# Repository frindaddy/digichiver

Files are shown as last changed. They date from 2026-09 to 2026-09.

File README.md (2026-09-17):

# Digichiver

Digichiver is an open hardware and software platform for operating, emulating,
and archiving the audio output of the National Semiconductor MM54104 Mozer
Digitalker speech synthesis system. The board can drive a physical MM54104,
serve historical speech ROM images through an RP2354B-based ROM emulator, and
record the resulting audio to a microSD card. Archived audio outputs are
available in the [Digitalker audio archive repository](https://github.com/frindaddy/digitalker-audio-archive).



## Repository Layout

The repository is organized by the part of the project it describes:

- `Hardware/` contains the KiCad schematics, PCB layout, custom footprints,
	fabrication outputs, and hardware design notes. Start with
	[`Hardware/readme.md`](Hardware/readme.md) for the circuit description.
- `Software/` contains the MicroPython firmware modules, ROM images, speech
	dictionaries, and archive configuration. Start with
	[`Software/readme.md`](Software/readme.md) for deployment and operation.
- `Simulation/` contains LTspice simulations for the analog speech filter.
- `DesignDocs/` contains project requirements and system architecture notes.
- `Datasheets/` contains component and reference documentation used by the
	design.
- `LICENSE` contains the project license.

## Using Digichiver

Digichiver requires the assembled board, an MM54104 Digitalker chip, and the
required ROM files for the speech vocabulary being used. The board is powered
and programmed over USB-C. Install the supplied
`Software/digichiver_firmware.uf2` firmware using the RP2354B USB bootloader,
then copy the required Python modules, ROM images, and JSON dictionaries from
`Software/` to the board's MicroPython filesystem.

After reset, connect to the board's MicroPython REPL. The software starts an
interactive `digichiver>` command loop for loading ROMs, speaking words,
checking word indexes, and archiving ROM groups to an inserted microSD card.
The complete command reference and file-deployment requirements are documented
in [`Software/readme.md`](Software/readme.md).

The hardware design can be opened with KiCad. The firmware `digitalker_firmware.u2f`
targets MicroPython on the RP2354B.

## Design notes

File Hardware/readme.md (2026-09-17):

# Circuit Description

The doc describes the digichicver circuit schematic (and PCB layout, when needed).

## Block Diagram

This sheet show the block diagram for the Digichiver board. The sheet is broken into 4 sections, the USB-C power/data connector, the Control block, the Digitalker block, the Audio block, and the Power block.

The USB-C connector is setup for a USB 2.0 full-speed connection, as that is the max capability of the RP2354B. Two $5.1k\Omega$ resistors tie `CC1` and `CC2` to ground to specify that this board is a power sink, per the USB specification. This advertises that this board can consume a maximum of 2.5W (5V@500mA).

## Control

This sheet shows the RP2354B and microSD card, as well as their supporting circuitry and pinouts.

### RP2354B

The RP2354B is the MCU on the Digichiver board and is used to control the MM54104 Digitalker chip, emulate Digitalker ROM modules, and record the Digitalker output audio to the microSD card (plus other basic GPIO functions). It interfaces with the MM54104 Digitalker chip, microSD card, and the PCM1809 audio recorder. The RP2354B has 2MB of internal flash in chip, so an external flash module is not required for operation.

#### RP2354B Power and Decoupling

The RP2354B nominally runs off a +3V3 supply, but requires a +1V1 rail for internal functions. Unlike its predecessor (the RP2340), the RP2354B ships with a built in switching regulator to generate this +1V1 rail in package, with the help of some supporting components. The design and layout of this power supply is strictly defined in [Hardware Design with the RP2350](https://pip-assets.raspberrypi.com/categories/1214-rp2350/documents/RP-008280-DS-1-hardware-design-with-rp2350.pdf), and the design recommendations were replicated here (part selection, connections, and layout).

Decoupling capacitors were placed based on the recommendations of [Hardware Design with the RP2350](https://pip-assets.raspberrypi.com/categories/1214-rp2350/documents/RP-008280-DS-1-hardware-design-with-rp2350.pdf); one for each power pin, and a special 4.7uF bulk cap for the +1V1 rail.

#### RP2354B USB Connection

The RP2354B is only capable of USB full speed (USB 2.0, 12Mbps, 48MHz clock). Though this is pretty slow speed, an attempt was made to keep the characteristic impedance of the USB traces close to the USB specification of $90\Omega$, differential. This board isn't being built with controlled impedances, so *rough* numbers are used for the calculation. To find the required trace width for a $90\Omega$ differential impedance, $Z_d$, we use the edge-coupled microstrip impedance equation.

$$Z_d \approx \frac{174}{\sqrt{\epsilon_r + 1.41}} \times \ln(\frac{5.98h}{0.8w + t}) \times [1-0.48^{-0.96\frac{s}{h}}]$$

where $Z_d$ is the differential impedance, $t$ is the trace thickness, $h$ is the height of the dielectric between the microstrip and ground plane, $s$ is the trace spacing, $\epsilon_r$ is the dielectric constant of the material, and $w$ is the trace width. The rough numbers are derived from the general JLCPCB 4 layer TG135 stackup and their manufacturing capabilities: $Z_d = 90\Omega$, $t = 1oz/ft^2$, $h = 8.283mil$, $s = 10mil$, and $\epsilon_r = 4.5$. Using these numbers, we calulate that the ideal trace width to achieve a $90\Omega$ differential impedance is `12.3645mil`.

$27\Omega$ series termination resistors are placed on the USB lines close to the RP2354B to meet the USB impedance specification.

#### RP2354B Clock

The RP2354B does not need an external clock to function (it ships with an internal oscillator), but a stable external frequency source greatly improves peripheral reliability and performance. As such, an external 12MHz crystal oscillator is used to clock the RP2354B. Part selection and circuit design are from the recommendations in [Hardware Design with the RP2350](https://pip-assets.raspberrypi.com/categories/1214-rp2350/documents/RP-008280-DS-1-hardware-design-with-rp2350.pdf).

#### Programming and Reset

Two pushbuttons, `SW1` and `SW2` are used to program and reset the RP2354B, respectively. When `SW1` is pressed on power up, the `QSPI_SS` line to the RP2354B is driven low, placing the device into programming mode. It will show up as a USB storage device, and a bootloader can be loaded into internal memory.

During operation, `SW2` can be pressed to reset the RP2354B by driving the `RUN` pin low.

#### Interfaces and GPIO

The MM54104 Digitalker control and ROM emulation busses take up most of the GPIO pins on the RP2354B. These signals are broken out as follows:

MM54104 Control Signals

| Signal | I/O | Pin Count |
| --- | --- | --- |
| SPC Word Selection Bus | O | 8 |
| SPC Chip Select | O | 1 |
| SPC Command Select | O | 1 |
| SPC Write Strobe | O | 1 |
| SPC Interrupt | I | 1 |

MM54104 ROM Emulation

| Signal | I/O | Pin Count |
| --- | --- | --- |
| ROM Address Bus | I | 14 |
| ROM Data Bus | O | 8 |
| ROMEN | I | 1 |

Because the MM54104 operates on +5V logic levels, these signals require level shifting. The level shifters are found on the Digitalker sheet.

An I2S interface connects the PCM1809 audio ADC to the RP2354B.

An SPI interface connects the RP2354B to the microSD card port.

One pushbutton, one green "Ready" LED, and one yellow "Activity" LED are connected to the RP2354B as GPIO.

### microSD Card

The RP2354B has an SPI connection to the microSD card header. An SPI connection was selected over the typical SDIO connection for a few reasons: all microSD cards support SPI communication, the higher speeds of the SDIO interface are not required for this application, and the SPI interface requries 4 pins instead of 6. The SPI bus connects to the SPI1 peripheral on the RP2354B, per the [RP2354B datasheet](https://pip-assets.raspberrypi.com/categories/1214-rp2350/documents/RP-008373-DS-2-rp2350-datasheet.pdf). 10k pullup resistors are added on each SPI line to keep the bus in a known state on bootup.

The card detect line `SD_DET` is routed as a GPIO input to the RP2354B to check if a microSD card is actually inserted before writing to it. The physical mechanism in the microSD card slot is a mechanical switch that connects pin `9` to pin `10` when a card is inserted into the slot ([per DM3AT-SF-PEJM5 datasheet](https://www.hirose.com/product/document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)). When a card is not installed, the `SD_DET` line is pulled low by `R32`. When a microSD card is inserted into the slot, the `SD_DET` line is driven high to +3V3.

## Digitalker

This sheet shows the MM54104 Digitalker Speech Processing Chip IC socket (`XC1`), required level shifting, and speech output filtering.

### MM54104

The MM54104 is designed to be socketed on the board, rather than soldered directly. This helps protect the rare MM54104 from any soldering induced temperature stress, and keeps it easily replaceable in the case of failure due to age.

The MM54104 is powered by +9V, with a 100nF decoupling capacitor placed close to the power input pin.

The MM54104 requires an external 4MHz clock for operation. Rather than add additonal components to the BOM, the `OSC_IN` pin is connected to one of the RP2354B PWM output ports through a level shifter. The 4MHz clock is generated by the RP2354B PWM controller.

### Level Shifting

The MM54104 runs on a +7-11V power input, although uses +5V compatable TTL logic for its I/O connections. As such, level shifting is required between the +3V3 CMOS I/O from the RP2354B and the +5V TTL logic from the MM54104. This level shifting is accomplished using two different part numbers.

For the MM54104 → RP2354B connections, the SN74LVC245A is used. This level shifter operates on a single +3V3 rail, but has +5V tolerant inputs. This single supply architecture not only simplifies the power plane routing on the board, but also reduces the total input capacitance on the +5V rail[^1]. A total of two are required to shift the `ROM_ADDR[0..13]`, `ROMEN`, and `INTR` lines. The SN74LVC245As are configured as always enabled, A → B mode.

[^1]: The reduction of input capacitance is beneficial as the USB specification states that power sinking devices should have no more than 10uF of input capacitance on the +5V power rail to limit inrush current and prevent damaging the power sourcing device. With some quick napkin math, one can determine that this board nominally has 11.3uF of input capacitance on the +5V rail, plus whatever parasitic capacitance is added from the traces in the layout. Looking at the decoupling and bulk capacitors used on the +5V rail, the 10uF cap (`C31`) is $\pm$20%, and the 1uF cap (`C33`) and 100nF caps (`C5`, `C6`, `C7`) are $\pm$10%, therefore worst case input capacitance is `13.43uF`, plus whatever parasitic capacitance exists. After testing the board in real life, this doesn't seem to be a problem.  

For the RP2354B → MM54104 connections, the SN74LVCBT245 is used. This level shifter operates on split +3V3 and +5V rails. A total of three are required to shift the `DIGITALKER_CLK_4MHZ`, `DIGITALKER_CS`, `DIGITALKER_WR`, `DIGITALKER_CMS`, `SW[1..8]`, and `RDATA[0..7]` lines. The SN74LVCBT245s are configured as always enabled, A → B mode.

### Speech Output Filter

The speech output filter is designed to produce the maximum frequency response for the MM54104 speech output. It features a voltage rebiasing network to shift the output down to +3V3 tolerant levels, and a dual-stage Sallen-Key filter to match the filtering recommendations in the DT1050 datasheet.

First, a 1uF input capacitor is used to decouple the audio stream from the ~+4VDC "silence voltage" output by the MM54104. The audio stream is then rebiased to a +1V65 DC voltage offset through a pullup resistor (`R23`) to `V_BIAS`, which is generated with a 2:1 voltage divider. A 100nF decoupling capactior (`C42`) is used to keep `V_BIAS` clean from any switching noise that may exist on the +3V3 rail. The rebiased audio output then goes through the first Sallen-Key filter, which is a 7,234Hz low pass filter. The output of the low-pass filter goes into the next Sallen-Key filter, a 194Hz high-pass filter. Combined, the rebiasing and filtering produce the a similar frequency response to that recommended by the D1050 datasheet.

LTSpice simulations for this filtering circuit can be found in `Digichiver/Simulation`.

## Audio

This sheet contains the three audio output sources (audio ADC, 3.5mm jack, and onboard speaker) and their associated circuitry. All outputs are AC coupled to the filtered speech line through 1uF capacitors.

### Audio ADC

To record the audio stream to the microSD card, the RP2354B requires an external audio ADC connected via an I2S bus. The PCM1809 is used for this.

The PCM1809 has two stereo inputs, but the MM54104 produces only a single mono output. As such, only the positive input on channel 1 of the PCM1809 is connected, with the channel 1 negative input and both channel 2 inputs capacitively coupled to ground, per [the PCM1809 datasheet](https://www.ti.com/lit/ds/symlink/pcm1809.pdf?ts=1723810813788).

The PCM1809 is configured in I2S target mode, therefore the RP2354B controls the bus/chip. The RP2354B generates the `BCLK` and `FSYNC` signals, and the PCM1809 dynamically adjusts its sampling rate based on the `BCLK` to `FSYNC` ratio. The output data is sent on the `SDATA` line.

Decoupling capacitors are selected based on the typical application in [the PCM1809 datasheet](https://www.ti.com/lit/ds/symlink/pcm1809.pdf?ts=1723810813788).

### 3.5mm Jack

The 3.5mm jack provides an output source to external speaker amplifiers, if desired. To make the mono audio signal compatable with a stereo TRS jack, the audio is split to the tip (`T`) and ring (`R`) pins of the jack through $100\Omega$ resistors. The resistors prevent dead shorts between the T and R pins if a non TRS cable is inserted into the jack. A $100k\Omega$ resistor weakly pulls the line to ground to help prevent popping on cable connection/disconnection.

### Onboard Speaker

The onboard speaker `LS1` is driven using a stereo class-D amplifier IC, the PAM8302A. This amplifier is capable of driving an $8\Omega$ speaker at just under 800mW when powered by a +3V3 rail. As such, the $8\Omega$ 780mW CMS-2821-078T onboard speaker is a solid choice due to its matching specifications and reasonbly even frequency response.

Because the PAM8302A expects a stereo input, the mono MM54014 output is fed into the positive input channel and the negative input channel is capacitively coupled to ground.

`RV1` is a $10k\Omega$ logarithmic potentiometer used to control the ultimate volume of the onboard speaker.

A GPIO line `SPEAKER_MUTE` is routed to the RP2354B so the speaker can be disabled by software, when required.

## Power

This sheet shows the two switching power supplies responsible for deriving the +3V3 and +9V power rails from the +5V input rail. Both designs are based on a combination of the typical application diagrams in their respective datasheets and designs generated using the Texas Instruments [WEBENCH® Power Designer](https://webench.ti.com/power-designer/) tool.

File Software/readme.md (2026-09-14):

# Digichiver Software

The software in this directory runs the Digichiver board on MicroPython for
the RP2354B. It drives the MM54104 control bus, emulates its parallel ROM
interface, provides dictionary-based speech, and records speech through the
PCM1809 audio ADC to a microSD card.

## Software Layout

- `main.py` starts the interactive `digichiver>` command loop.
- `board.py` assigns the RP2354B GPIO, PWM, SPI, and I2S interfaces used by the
  board.
- `digitalker.py` drives the MM54104 word-selection bus and control signals.
- `rom_emulator.py` serves a selected ROM image using PIO and DMA without
  requiring Python to handle each ROM access.
- `free_speak.py` resolves text, aliases, numbers, and literal vocabulary
  fragments into Digitalker words.
- `archive.py` captures 48 kHz, 16-bit, mono PCM and writes WAV files to `/sd`.
- `sdcard.py` provides the SPI microSD-card driver.
- `Dictionaries/` contains the free-speak vocabulary, archive metadata, and
  index-to-word dictionaries.
- `ROMs/` contains the supplied ROM image collections and source indexes.
- `digichiver_firmware.uf2` is the firmware image for the RP2354B.

## Deployment

Install `digichiver_firmware.uf2` with the RP2354B USB bootloader. After the
board resets, copy the runtime files to the MicroPython filesystem. The
working directory matters because the software opens ROMs and JSON files by
filename, so the following files must be in one flat directory on the board:

```text
archive.py
archive_config.json
board.py
digitalker.py
free_speak.py
free_speak_dictionary.json
main.py
rom_emulator.py
sdcard.py
```

Copy the ROM files required by the selected operation into that same
directory. For `/say` and `/say_all`, also copy `DVSSROM1.bin` through
`DVSSROM5.bin`. For `/archive`, copy the source ROMs and dictionary files
named by `Dictionaries/archive_config.json`. Reset the board and connect to its
MicroPython REPL; `main.py` starts the command loop.

## ROM Emulator

`RomEmulator` presents a selected binary image as the MM54104's 16 KiB
parallel ROM. A single image may contain from 1 to 16 KiB. It is loaded at
address `0x0000` and zero-filled through `0x3fff`. Two-file images must contain
exactly 8 KiB per file and are concatenated in argument order.

```python
from rom_emulator import RomEmulator

rom = RomEmulator()
rom.load("DT1052.bin")
rom.load("SSR1.bin", "SSR2.bin")
```

`load()` validates the new files before stopping a currently running image.
An invalid reload leaves the previous image running. If the new image cannot
start, it remains selected but stopped. File paths are resolved from the
MicroPython working directory.

## Free Speak

`free_speak.py` maps text to the five DVSS ROMs and their word indexes. Input
is case-insensitive and runs of whitespace are collapsed. The complete input
is resolved before any ROM is loaded or word is spoken, so an unknown word
does not produce partial speech.

```python
from digitalker import Digitalker
from free_speak import free_speak
from rom_emulator import RomEmulator

rom = RomEmulator()
digitalker = Digitalker()
free_speak("emergency enable", rom, digitalker)
```

The dictionary supports canonical entries and explicit aliases such as
`thank you` and `wake up`. Numeric input accepts signs, comma-separated
integers, leading zeroes, and decimal fractions. Values are converted to
available vocabulary words; values above one billion are spoken digit by
digit. Unknown words may also resolve through one literal prefix, exact root,
and suffix composition. The `composition` and `numbers` sections of
`Dictionaries/free_speak_dictionary.json` define these mappings.

The dictionary was generated from `ROMs/DVSS/DVSS_ROMS_INDEX.pdf`. Its
pronunciation suffixes are recorded vocabulary labels, not automatic grammar
rules: the runtime does not strip suffixes or select variants by itself.

## REPL Commands

`main.py` creates the ROM emulator and Digitalker driver, then accepts commands
at the `digichiver>` prompt:

```text
/load_rom SSR1.bin SSR2.bin
/say hello this is my speech
/say_index 42
/say_index 0 50
/say_all
/archive ssr1/ssr2
```

- `/load_rom <file1> [file2]` loads one ROM image or two 8 KiB banks.
- `/say <text>` speaks text through the DVSS free-speak dictionary.
- `/say_index <start> [end]` speaks one index or an inclusive range from 0
  through 255. Decimal and `0x` hexadecimal indexes are accepted.
- `/say_all` speaks every word in the free-speak vocabulary.
- `/archive <group>` records a configured ROM group to the microSD card.
- `/help` prints the command list.
- `/exit` and `/quit` leave the command loop.

## ROM Archiving

Archiving requires an inserted microSD card. The archive groups and their ROM
sources are defined in `Dictionaries/archive_config.json`:

```text
/archive ssr1/ssr2
```

Groups with an index-to-word dictionary produce `/sd/<group>/<index>_<word>.wav`.
DVSS groups set `include_index` to false and write word-named files. Groups
without a known dictionary use `/sd/<group>/<index>.wav`. Files are 48 kHz,
16-bit, mono PCM recorded from the PCM1809 I2S input around each Digitalker
word. Genesis and Jameco JE-520 images are represented as separate bank
passes, such as `genesis-1`, `genesis-2`, `je520-1`, and `je520-2`.

## ROM Image Sources

The DVSS ROM images were converted from Intel HEX files and are provided as a
contribution from [@MarkD833](https://github.com/MarkD833), whose source
archive is the [Digitalker Digital Voice Selection Software repository](https://github.com/MarkD833/Digitalker-Digital-Voice-Selection-Software).
Other ROM images are sourced from the [Internet Archive](https://archive.org/details/digitalker).

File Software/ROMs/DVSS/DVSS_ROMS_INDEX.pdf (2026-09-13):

## National Semiconductor

Digital Voice Selection Software (DTSW-500)

This document contains a list of all the vocabulary numbers, letters, words and sounds etc that were included with the National Semiconductor Digitalker Digital Voice Selection Software program suite.

There are over 600 to choose from when creating your own custom ROMs. As far as know, there are no other vocabulary libraries available.

I have split the complete library of words into 5 ROMs.

Each ROM is a maximum of 16Kbytes in size. Attempting to exceed 16Kbytes results in errors being reported.

The 5 ROMs files are all in Intel-HEX format and named:

- DVSSROM1.HEX
- DVSSROM2.HEX
- DVSSROM3.HEX
- DVSSROM4.HEX
- DVSSROM5.HEX

There is a 6th ROM called DVSSROMS.HEX which is all 5 ROMs merged into 1 file which can be programmed into a larger flash chip if your hardware supports one big chip for the vocabulary.

What follows are the lists of vocabulary words in each ROM along with their respective “addresses”. If you want Digitalker to say the word “emergency” from ROM #2, then you need to tell the Digitalker chip to speak word 53.

If you have combined all the ROMs and programmed 1 big ROM, then you will need to select the required ROM using whatever technique your hardware uses.

Created by @markd833 (forum.arduino.cc) on 13-DEC-2023

### DVSSROM #1 INDEX

1 -ed.fs1
2 -ed.fs2
3 -ed.fs3
4 -ed.fs4
5 -er.ms1
6 -er.ms2
7 -er.ms3
8 -er.ms4
9 -er.ms5
10 -ing.fs1
11 -ing.fs2
12 -ing.ms3
13 -s.ms1
14 -s.ms2
15 -th.ms
16 -uth.ms
17 0
18 1
19 10
20 100
21 1000
22 11
23 12
24 13
25 14
26 15
27 16
28 17
29 18
30 19
31 2
32 20
33 3
34 30
35 4
36 40
37 5
38 50
39 6
40 60
41 7
42 70
43 8
44 80
45 9
46 90

### 47 a 48 a-.fgt

49 a-.mqr 50 a-.rqt 51 able 52 abort 53 aborted 54 ac 55 accumulate 56 acknowledge 57 activate 58 activating.s 59 active 60 activity 61 add.r 62 address 63 adjust.s 64 after 65 after.p 66 after.r 67 again 68 air 69 aisle 70 alarm 71 alarm.r 72 alert 73 all.r 74 alternate.sa 75 am(time) 76 amp 77 ampere 78 an 79 and 80 announcement 81 answer.s 82 april.r 83 arrival 84 ask 85 ask.r 86 assistance 87 astern 88 at 89 at.ft 90 at.r 91 attention 92 august.r 93 authorize 94 auto 95 available.r 96 average

### 97 away 98 b 99 back

100 barometric.r
101 basement
102 bath
103 battery
104 been.r
105 before.r
106 between.r
107 black
108 blocking
109 blue
110 brake
111 budget.s
112 budgeting
113 building
114 buoy
115 busy
116 button
117 buy
118 by.r
119 c
120 call
121 cancel
122 capacitance
123 car
124 case
125 caution
126 cease
127 celsius
128 cent
129 centi-.fp
130 centigrade
131 centimeter
132 change
133 channel.r
134 check.r
135 circuit
136 clear
137 close
138 close.r
139 closed
140 closed.r
141 code
142 cold
143 comma

### DVSS ROM#2 INDEX

1 command.r 2 common 3 communication 4 complete 5 condition 6 configuration 7 connect.r 8 continue.s 9 control 10 converter 11 cool 12 copy 13 correct 14 cost.r 15 count.r 16 cross 17 customer 18 cut.mt 19 cutting 20 d 21 danger.fue 22 data 23 date 24 day 25 dc 26 december.r 27 decrease.r 28 default 29 degree 30 delay.r 31 demonstration 32 deposit.r 33 depth 34 dial 35 dial.r 36 dialing.s 37 did.r 38 disable 39 disabled 40 divide 41 dollar 42 door 43 down 44 e 45 east 46 eight 47 eighteen 48 eighty

49 electric 50 electricity 51 eleven 52 else 53 emergency 54 enable 55 enabled 56 end.r 57 enter 58 entry 59 equal 60 error 61 evacuate 62 examine 63 exit 64 exit.r 65 extreme 66 f 67 fail 68 failed 69 failure 70 far 71 farad 72 fast 73 faster 74 february.r 75 feet 76 fifteen 77 fifth 78 fifty 79 fight 80 fire 81 fire.fe 82 first 83 five 84 floor 85 flow 86 forty 87 forward 88 four 89 fourteen 90 friday 91 from 92 frontal.m 93 fuel 94 fuse 95 fused 96 g

### 97 gallon 98 gas 99 get

100 go
101 going
102 good.m
103 gram
104 gray
105 great
106 greater
107 green
108 group
109 h
110 half
111 have
112 hello.p
113 help
114 here
115 hertz
116 high
117 higher
118 hire
119 hit
120 hold
121 home
122 hour
123 house
124 hundred
125 hurt
126 i
127 if.r
128 in
129 in.r
130 in-.mpt
131 in-.rp
132 inactive

### DVSS ROM#3 INDEX

1 inches 2 incorporated 3 incorrect 4 increase.r 5 insert.r 6 interface 7 intruder 8 invalid.fa 9 is.r 10 it 11 j 12 january.r 13 july.r 14 june.r 15 just.s 16 k 17 key 18 keypad 19 kilo-.fp 20 l 21 leave.s 22 left 23 less 24 lesser 25 level 26 lie 27 light 28 lime 29 limit 30 line 31 link 32 listen.r 33 load 34 lock 35 locked 36 loop 37 looped 38 low 39 lower 40 m 41 march.r 42 mark 43 may.r 44 meg-.rp 45 mega-.rp 46 message 47 message.r 48 meter

49 micro-.rp 50 mile 51 milli-.mp 52 millimeter 53 million 54 minus 55 minute 56 miss 57 missing 58 model 59 modem 60 module 61 monday 62 monitor 63 more 64 move.m 65 move.r 66 my.m 67 n 68 nano-.rp 69 near 70 need 71 next 72 next.m 73 night 74 nine 75 nineteen 76 ninety 77 no.m 78 normal 79 north 80 not 81 notice 82 november.r 83 number 84 o 85 o'clock 86 october.r 87 of 88 off 89 ohm 90 okay 91 on 92 one 93 onward 94 open 95 operator 96 optical

### 97 optical.m 98 or 99 other.s

100 out
101 over
102 over-range
103 p
104 pair
105 pan
106 parenthesis
107 pass
108 pass.r
109 passed
110 past
111 per.r
112 per-.sp
113 percent
114 phone.r
115 phone-number
116 pico-.rp
117 place
118 place.s
119 play
120 please
121 please.p
122 plus
123 pm
124 point
125 point.r
126 pound
127 power
128 present

### DVSS ROM#4 INDEX

1 press.r 2 pressure 3 program 4 pull.r 5 pulse.m 6 pulses 7 push.r 8 put.s 9 q 10 quarter 11 r 12 rain 13 range 14 rate 15 re-.mph 16 re-.mpl 17 re-.sph 18 re-.spl 19 reach 20 ready 21 received.r 22 receiver 23 record.r 24 red 25 remove.s 26 repair.r 27 repeat 28 replace.p 29 replace.r 30 reset 31 resistance 32 response 33 restore 34 restored 35 return.s 36 reverse 37 right 38 ring 39 ring.r 40 room 41 route 42 run 43 running 44 s 45 safe 46 saturday 47 second 48 secure

49 security 50 see 51 select 52 send.r 53 sensor 54 sent 55 september.r 56 sequence.m 57 service 58 set 59 seven 60 seventeen 61 seventy 62 short 63 should.m 64 side 65 sight 66 sil10 67 sil160 68 sil20 69 sil320 70 sil40 71 sil5 72 sil640 73 sil80 74 sink 75 site 76 six 77 sixteen 78 sixty 79 slow 80 slower 81 smile 82 smoke 83 sound 84 south 85 space 86 span 87 spare 88 speed 89 spell 90 squad 91 squad.m 92 stair 93 star 94 start 95 station 96 status

### 97 steam 98 stern 99 stop

100 store
101 storm
102 stream
103 street
104 sub
105 subscriber
106 sunday
107 supervisory
108 switch
109 switched
110 system.r
111 t
112 tank
113 tape
114 taping
115 target.s
116 tea
117 tear
118 teen
119 temperature
120 temporary.s
121 ten
122 terminate
123 terminated
124 test
125 than
126 thank
127 thank.m
128 thank-you
129 that.r
130 the.r
131 the-.mr
132 the-.rt
133 the-.st
134 thee.r
135 thee-.mr
136 thee-.rt
137 then.r
138 there
139 therm

### DVSS ROM#5 INDEX

1 thermal 2 thermal.m 3 third 4 thirteen 5 thirty 6 this.m 7 thousand 8 three 9 thursday 10 tide 11 time.r 12 tip 13 today.r 14 today's.r 15 tone 16 tone1000 17 tone1000.mt 18 tone10000 19 tone10000.mt 20 tone12500 21 tone12500.mt 22 tone200 23 tone200.mt 24 tone2000 25 tone2000.mt 26 tone400 27 tone400.mt 28 tone5000 29 tone5000.mt 30 tone80 31 tone80.mt 32 tone800 33 tone800.mt 34 total 35 touch.r 36 tracking.s 37 traffic 38 transfer.m 39 trip 40 true.r 41 trunk 42 try 43 tuesday 44 turn 45 turn.s 46 twelve 47 twenty 48 two

49 type 50 u 51 un-.rp1 52 un-.rp2 53 unable 54 unattended 55 unit 56 unknown 57 unlock 58 unlocked 59 untrue.r 60 up 61 use 62 use.r 63 used 64 utility 65 v 66 voice 67 volt 68 voltage 69 vote 70 w 71 wait 72 wait.r 73 waiting 74 waiting.s 75 wake 76 wake-up 77 warm 78 warning 79 was.s 80 water 81 watt 82 wave 83 wear 84 wednesday 85 week.s 86 welcome 87 west 88 what.r 89 will.r 90 wind.fnq 91 wind.rvg 92 wish.r 93 with.r 94 within.r 95 word 96 work

### 97 working 98 x 99 y

100 yellow
101 yes
102 yes.m
103 you
104 your.r
105 z
106 zero
107 zone

### DVSS ROM Build Reports

There are the actual build reports for each of the 5 ROMs as reported by the DVSS software.

### DVSSROM #1

Message pointers: 144 (288 bytes)
Instructions: 1082 (3246 bytes) Speech data used: 12694 bytes Speech data reused: 26439 bytes

Total bytes used: 16228 (100%) Total bytes left: 156 (0%)

### DVSSROM #2

Message pointers: 133 (266 bytes) Instructions: 1076 (3228 bytes) Speech data used: 12783 bytes Speech data reused: 25439 bytes

Total bytes used: 16277 (100%) Total bytes left: 107 (0%)

### DVSSROM #3

Message pointers: | 129 (258 bytes)
Instructions: | 972 (2916 bytes)
Speech data used: 13156 bytes Speech data reused: 19520 bytes

Total bytes used: 16330 (100%) Total bytes left: 54 (0%)

### DVSSROM #4

Message pointers: 140 (280 bytes) Instructions: 1281 (3843 bytes) Speech data used: 12154 bytes Speech data reused: 36352 bytes

Total bytes used: 16277 (100%) Total bytes left: 107 (0%)

### DVSSROM #5

Message pointers: | 108 (216 bytes)
Instructions: | 787 (2361 bytes)
Speech data used: 9988 bytes Speech data reused: 15893 bytes

Total bytes used: 12565 (77%)
Total bytes left: 3819 (23%)

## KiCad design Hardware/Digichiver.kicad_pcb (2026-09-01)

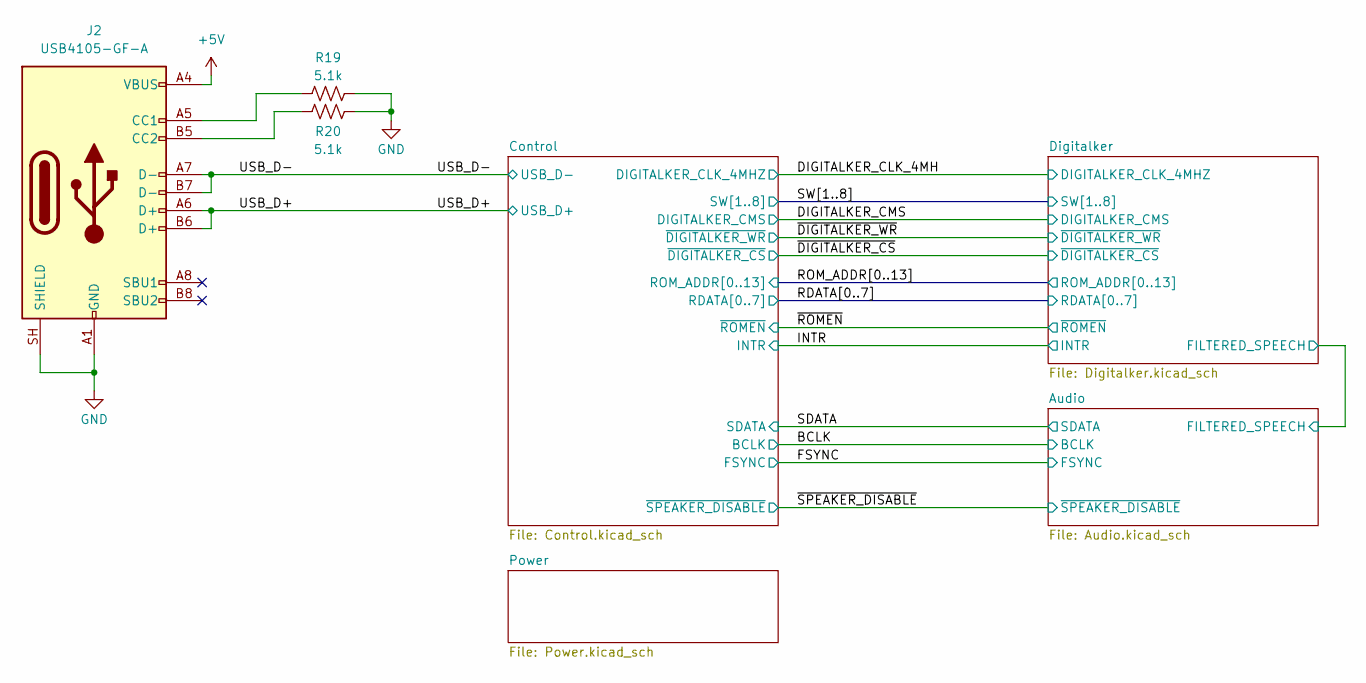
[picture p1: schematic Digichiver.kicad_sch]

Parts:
J2: USB4105-GF-A; USB_C_Receptacle_GCT_USB4105-xx-A_16P_TopMnt_Horizontal; MPN USB4105-GF-A; JLCPCB Part # C3020560
R19, R20: 5.1k; R_0402_1005Metric; MPN 0402WGF5101TCE; JLCPCB Part # C25905

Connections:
+5V: J2.A4 (VBUS), J2.A9 (VBUS), J2.B4 (VBUS), J2.B9 (VBUS); also elsewhere on the board
/USB_D+: J2.A6 (D+), J2.B6 (D+); also elsewhere on the board
/USB_D-: J2.A7 (D-), J2.B7 (D-); also elsewhere on the board
GND: J2.A1 (GND), J2.A12 (GND), J2.B1 (GND), J2.B12 (GND), J2.SH (SHIELD), R19.1, R20.1; also elsewhere on the board
unnamed: J2.A5 (CC1), R19.2
unnamed: J2.B5 (CC2), R20.2

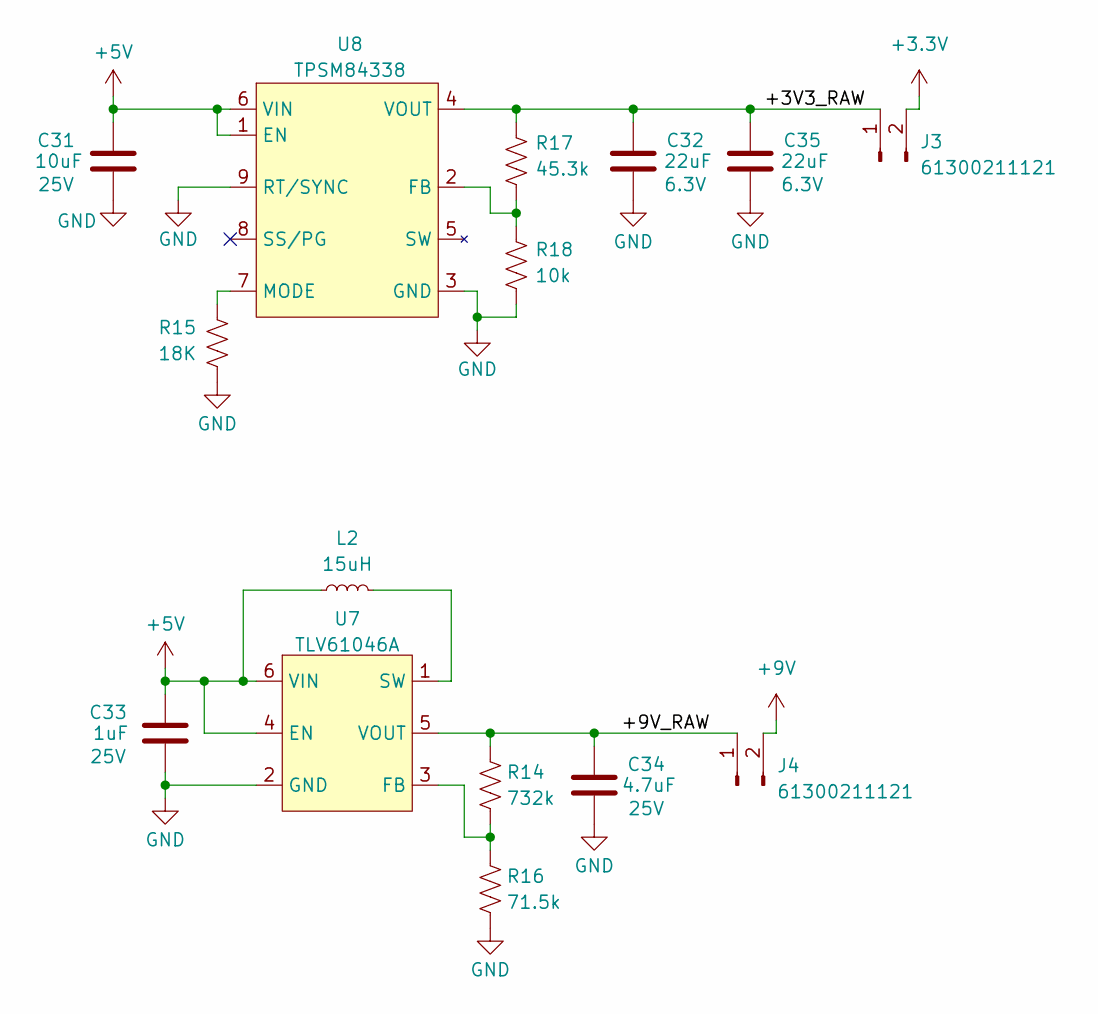
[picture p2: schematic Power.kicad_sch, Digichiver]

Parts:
C31: 10uF; C_0603_1608Metric; Voltage 25V; MPN CL10A106MA8NRNC; JLCPCB Part # C96446
C32, C35: 22uF; C_0603_1608Metric; Voltage 6.3V; MPN CL10A226MQ8NRNC; JLCPCB Part # C59461
C33: 1uF; C_0402_1005Metric; Voltage 25V; MPN CL05A105KA5NQNC; JLCPCB Part # C52923
C34: 4.7uF; C_0805_2012Metric; Voltage 25V; MPN CL21A475KAQNNNE; JLCPCB Part # C1779
J3, J4: 61300211121; PinHeader_1x02_P2.54mm_Vertical; MPN 61300211121; JLCPCB Part # C2915055
L2: 15uH; IND_VLCF4020T-150MR68; MPN VLCF4020T-150MR68; JLCPCB Part # C695173
R14: 732k; R_0402_1005Metric; MPN RC0402FR-07732KL; JLCPCB Part # C137940
R15: 18K; R_0402_1005Metric; MPN 0402WGF1802TCE; JLCPCB Part # C25762
R16: 71.5k; R_0402_1005Metric; MPN RC0402FR-0771K5L; JLCPCB Part # C273328
R17: 45.3k; R_0402_1005Metric; MPN RC0402FR-0745K3L; JLCPCB Part # C137977
R18: 10k; R_0402_1005Metric; MPN 0402WGF1002TCE; JLCPCB Part # C25744
U7: TLV61046A; SOT-23-6; MPN TLV61046A; JLCPCB Part # C139398
U8: TPSM84338; CONV_TPSM84338RCJR; MPN TPSM84338; JLCPCB Part # C47122151

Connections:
+3.3V: J3.2; also elsewhere on the board
+5V: C31.1, C33.1, L2.1, U7.4 (EN), U7.6 (VIN), U8.1 (EN), U8.6 (VIN); also elsewhere on the board
+9V: J4.2; also elsewhere on the board
/Power/+3V3_RAW: C32.1, C35.1, J3.1, R17.1, U8.4 (VOUT)
/Power/+9V_RAW: C34.1, J4.1, R14.1, U7.5 (VOUT)
GND: C31.2, C32.2, C33.2, C34.2, C35.2, R15.2, R16.2, R18.2, U7.2 (GND), U8.3 (GND), U8.9 (RT/SYNC); also elsewhere on the board
unnamed: R14.2, R16.1, U7.3 (FB)
unnamed: L2.2, U7.1 (SW)
unnamed: R17.2, R18.1, U8.2 (FB)
unnamed: R15.1, U8.7 (MODE)

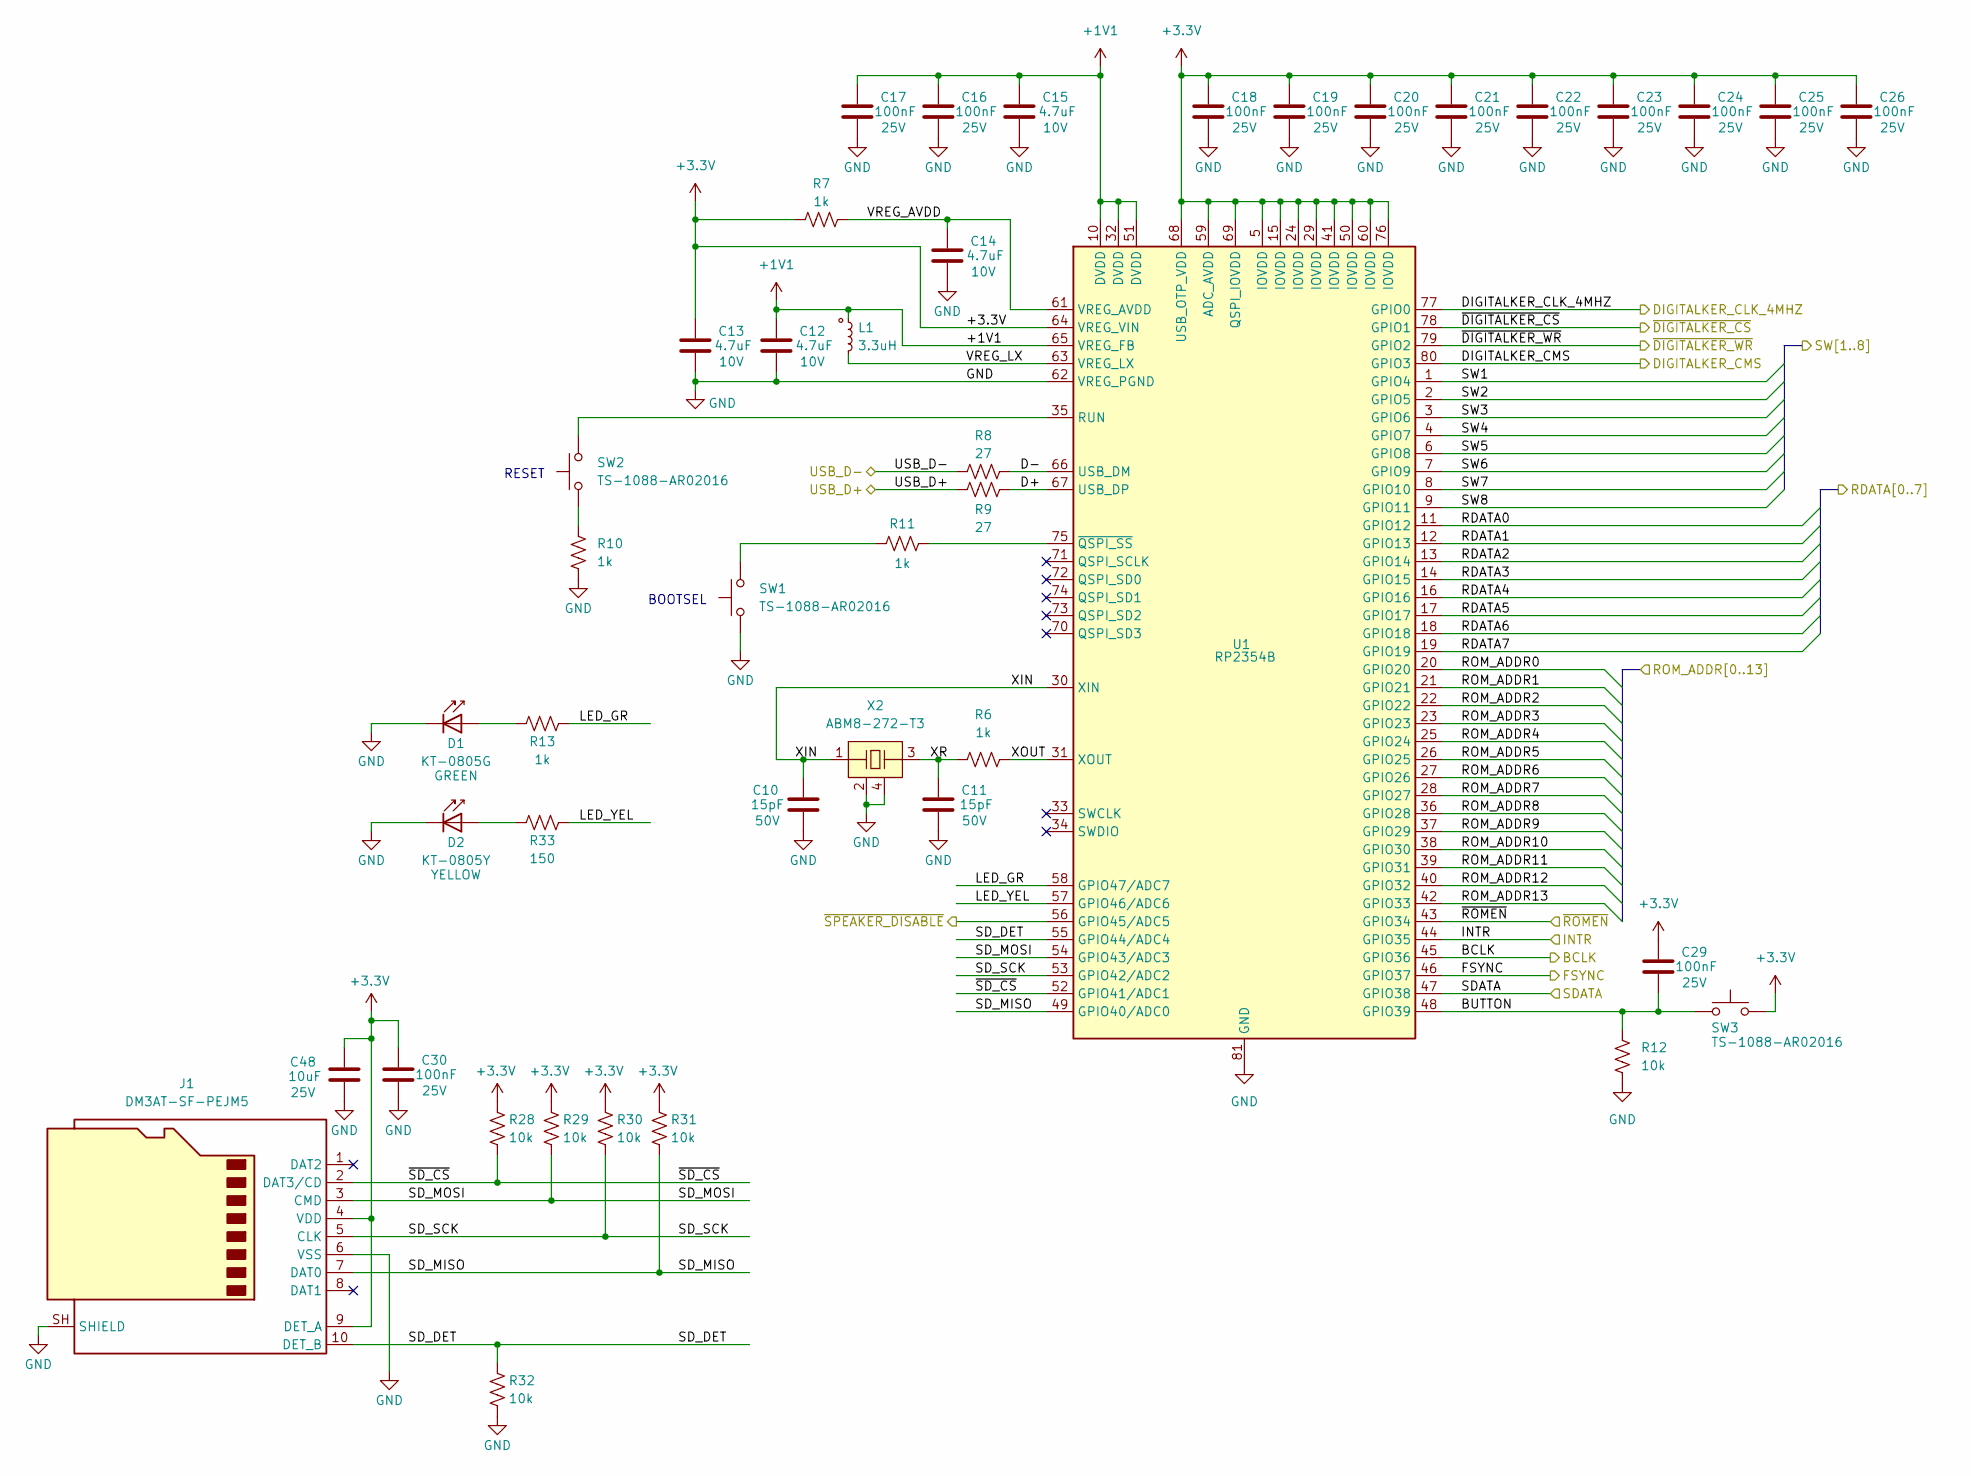
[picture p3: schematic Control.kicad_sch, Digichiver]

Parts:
C10, C11: 15pF; C_0402_1005Metric; Voltage 50V; MPN 0402CG150J500NT; JLCPCB Part # C1548
C12, C13, C14, C15: 4.7uF; C_0402_1005Metric; Voltage 10V; MPN CL05A475MP5NRNC; JLCPCB Part # C23733
C16, C17, C18, C19, C20, C21, C22, C23, C24, C25, C26, C29, C30: 100nF; C_0402_1005Metric; Voltage 25V; MPN CL05B104KB54PNC; JLCPCB Part # C307331
C48: 10uF; C_0603_1608Metric; Voltage 25V; MPN CL10A106MA8NRNC; JLCPCB Part # C96446
D1: KT-0805G; LED_0805_2012Metric; MPN KT-0805G; JLCPCB Part # C2297
D2: KT-0805Y; LED_0805_2012Metric; MPN KT-0805Y; JLCPCB Part # C2296
J1: DM3AT-SF-PEJM5; microSD_HC_Hirose_DM3AT-SF-PEJM5; MPN DM3AT-SF-PEJM5; JLCPCB Part # C114218
L1: 3.3uH; L_0805_2012Metric; MPN AOTA-B201610S3R3-101-T; JLCPCB Part # C42411119
R6, R7, R10, R11, R13: 1k; R_0402_1005Metric; MPN 0402WGF1001TCE; JLCPCB Part # C11702
R8, R9: 27; R_0603_1608Metric; MPN 0603WAF270JT5E; JLCPCB Part # C25190
R12, R28, R29, R30, R31, R32: 10k; R_0402_1005Metric; MPN 0402WGF1002TCE; JLCPCB Part # C25744
R33: 150; R_0402_1005Metric; MPN 0402WGF1500TCE; JLCPCB Part # C25082
SW1, SW2, SW3: TS-1088-AR02016; SW_SPST_TS-1088-xR020; MPN TS-1088-AR02016; JLCPCB Part # C720477
U1: RP2354B; QFN-80-1EP_10x10mm_P0.4mm_EP3.4x3.4mm; MPN RP2354B; JLCPCB Part # C39843328
X2: ABM8-272-T3; Crystal_SMD_Abracon_ABM8G-4Pin_3.2x2.5mm; MPN ABM8-272-T3; JLCPCB Part # C20625731

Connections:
+1V1: C12.1, C15.1, C16.1, C17.1, L1.1, U1.10 (DVDD), U1.32 (DVDD), U1.51 (DVDD), U1.65 (VREG_FB)
+3.3V: C13.1, C18.1, C19.1, C20.1, C21.1, C22.1, C23.1, C24.1, C25.1, C26.1, C29.1, C30.1, C48.1, J1.4 (VDD), J1.9 (DET_A), R7.2, R28.2, R29.2, R30.2, R31.2, SW3.2, U1.5 (IOVDD), U1.15 (IOVDD), U1.24 (IOVDD), U1.29 (IOVDD), U1.41 (IOVDD), U1.50 (IOVDD), U1.59 (ADC_AVDD), U1.60 (IOVDD), U1.64 (VREG_VIN), U1.68 (USB_OTP_VDD), U1.69 (QSPI_IOVDD), U1.76 (IOVDD); also elsewhere on the board
/BCLK: U1.45 (GPIO36); also elsewhere on the board
/Control/BUTTON: C29.2, R12.1, SW3.1, U1.48 (GPIO39)
/Control/D+: R9.1, U1.67 (USB_DP)
/Control/D-: R8.1, U1.66 (USB_DM)
/Control/LED_GR: R13.1, U1.58 (GPIO47/ADC7)
/Control/LED_YEL: R33.1, U1.57 (GPIO46/ADC6)
/Control/SD_DET: J1.10 (DET_B), R32.2, U1.55 (GPIO44/ADC4)
/Control/SD_MISO: J1.7 (DAT0), R31.1, U1.49 (GPIO40/ADC0)
/Control/SD_MOSI: J1.3 (CMD), R29.1, U1.54 (GPIO43/ADC3)
/Control/SD_SCK: J1.5 (CLK), R30.1, U1.53 (GPIO42/ADC2)
/Control/VREG_AVDD: C14.1, R7.1, U1.61 (VREG_AVDD)
/Control/VREG_LX: L1.2, U1.63 (VREG_LX)
/Control/XIN: C10.1, U1.30 (XIN), X2.1
/Control/XOUT: R6.1, U1.31 (XOUT)
/Control/XR: C11.1, R6.2, X2.3
/Control/~SD_CS: J1.2 (DAT3/CD), R28.1, U1.52 (GPIO41/ADC1)
/DIGITALKER_CLK_4MH: U1.77 (GPIO0); also elsewhere on the board
/DIGITALKER_CMS: U1.80 (GPIO3); also elsewhere on the board
/FSYNC: U1.46 (GPIO37); also elsewhere on the board
/INTR: U1.44 (GPIO35); also elsewhere on the board
/RDATA0: U1.11 (GPIO12); also elsewhere on the board
/RDATA1: U1.12 (GPIO13); also elsewhere on the board
/RDATA2: U1.13 (GPIO14); also elsewhere on the board
/RDATA3: U1.14 (GPIO15); also elsewhere on the board
/RDATA4: U1.16 (GPIO16); also elsewhere on the board
/RDATA5: U1.17 (GPIO17); also elsewhere on the board
/RDATA6: U1.18 (GPIO18); also elsewhere on the board
/RDATA7: U1.19 (GPIO19); also elsewhere on the board
/ROM_ADDR0: U1.20 (GPIO20); also elsewhere on the board
/ROM_ADDR1: U1.21 (GPIO21); also elsewhere on the board
/ROM_ADDR2: U1.22 (GPIO22); also elsewhere on the board
/ROM_ADDR3: U1.23 (GPIO23); also elsewhere on the board
/ROM_ADDR4: U1.25 (GPIO24); also elsewhere on the board
/ROM_ADDR5: U1.26 (GPIO25); also elsewhere on the board
/ROM_ADDR6: U1.27 (GPIO26); also elsewhere on the board
/ROM_ADDR7: U1.28 (GPIO27); also elsewhere on the board
/ROM_ADDR8: U1.36 (GPIO28); also elsewhere on the board
/ROM_ADDR9: U1.37 (GPIO29); also elsewhere on the board
/ROM_ADDR10: U1.38 (GPIO30); also elsewhere on the board
/ROM_ADDR11: U1.39 (GPIO31); also elsewhere on the board
/ROM_ADDR12: U1.40 (GPIO32); also elsewhere on the board
/ROM_ADDR13: U1.42 (GPIO33); also elsewhere on the board
/SDATA: U1.47 (GPIO38); also elsewhere on the board
/SW1: U1.1 (GPIO4); also elsewhere on the board
/SW2: U1.2 (GPIO5); also elsewhere on the board
/SW3: U1.3 (GPIO6); also elsewhere on the board
/SW4: U1.4 (GPIO7); also elsewhere on the board
/SW5: U1.6 (GPIO8); also elsewhere on the board
/SW6: U1.7 (GPIO9); also elsewhere on the board
/SW7: U1.8 (GPIO10); also elsewhere on the board
/SW8: U1.9 (GPIO11); also elsewhere on the board
/USB_D+: R9.2; also elsewhere on the board
/USB_D-: R8.2; also elsewhere on the board
/~DIGITALKER_CS: U1.78 (GPIO1); also elsewhere on the board
/~DIGITALKER_WR: U1.79 (GPIO2); also elsewhere on the board
/~ROMEN: U1.43 (GPIO34); also elsewhere on the board
/~SPEAKER_DISABLE: U1.56 (GPIO45/ADC5); also elsewhere on the board
GND: C10.2, C11.2, C12.2, C13.2, C14.2, C15.2, C16.2, C17.2, C18.2, C19.2, C20.2, C21.2, C22.2, C23.2, C24.2, C25.2, C26.2, C30.2, C48.2, D1.1 (K), D2.1 (K), J1.6 (VSS), J1.SH (SHIELD), R10.1, R12.2, R32.1, SW1.1, U1.62 (VREG_PGND), U1.81 (GND), X2.2, X2.4; also elsewhere on the board
unnamed: D1.2 (A), R13.2
unnamed: D2.2 (A), R33.2
unnamed: R10.2, SW2.1
unnamed: R11.2, SW1.2
unnamed: SW2.2, U1.35 (RUN)
unnamed: R11.1, U1.75 (~QSPI_SS)

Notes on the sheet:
RESET
BOOTSEL

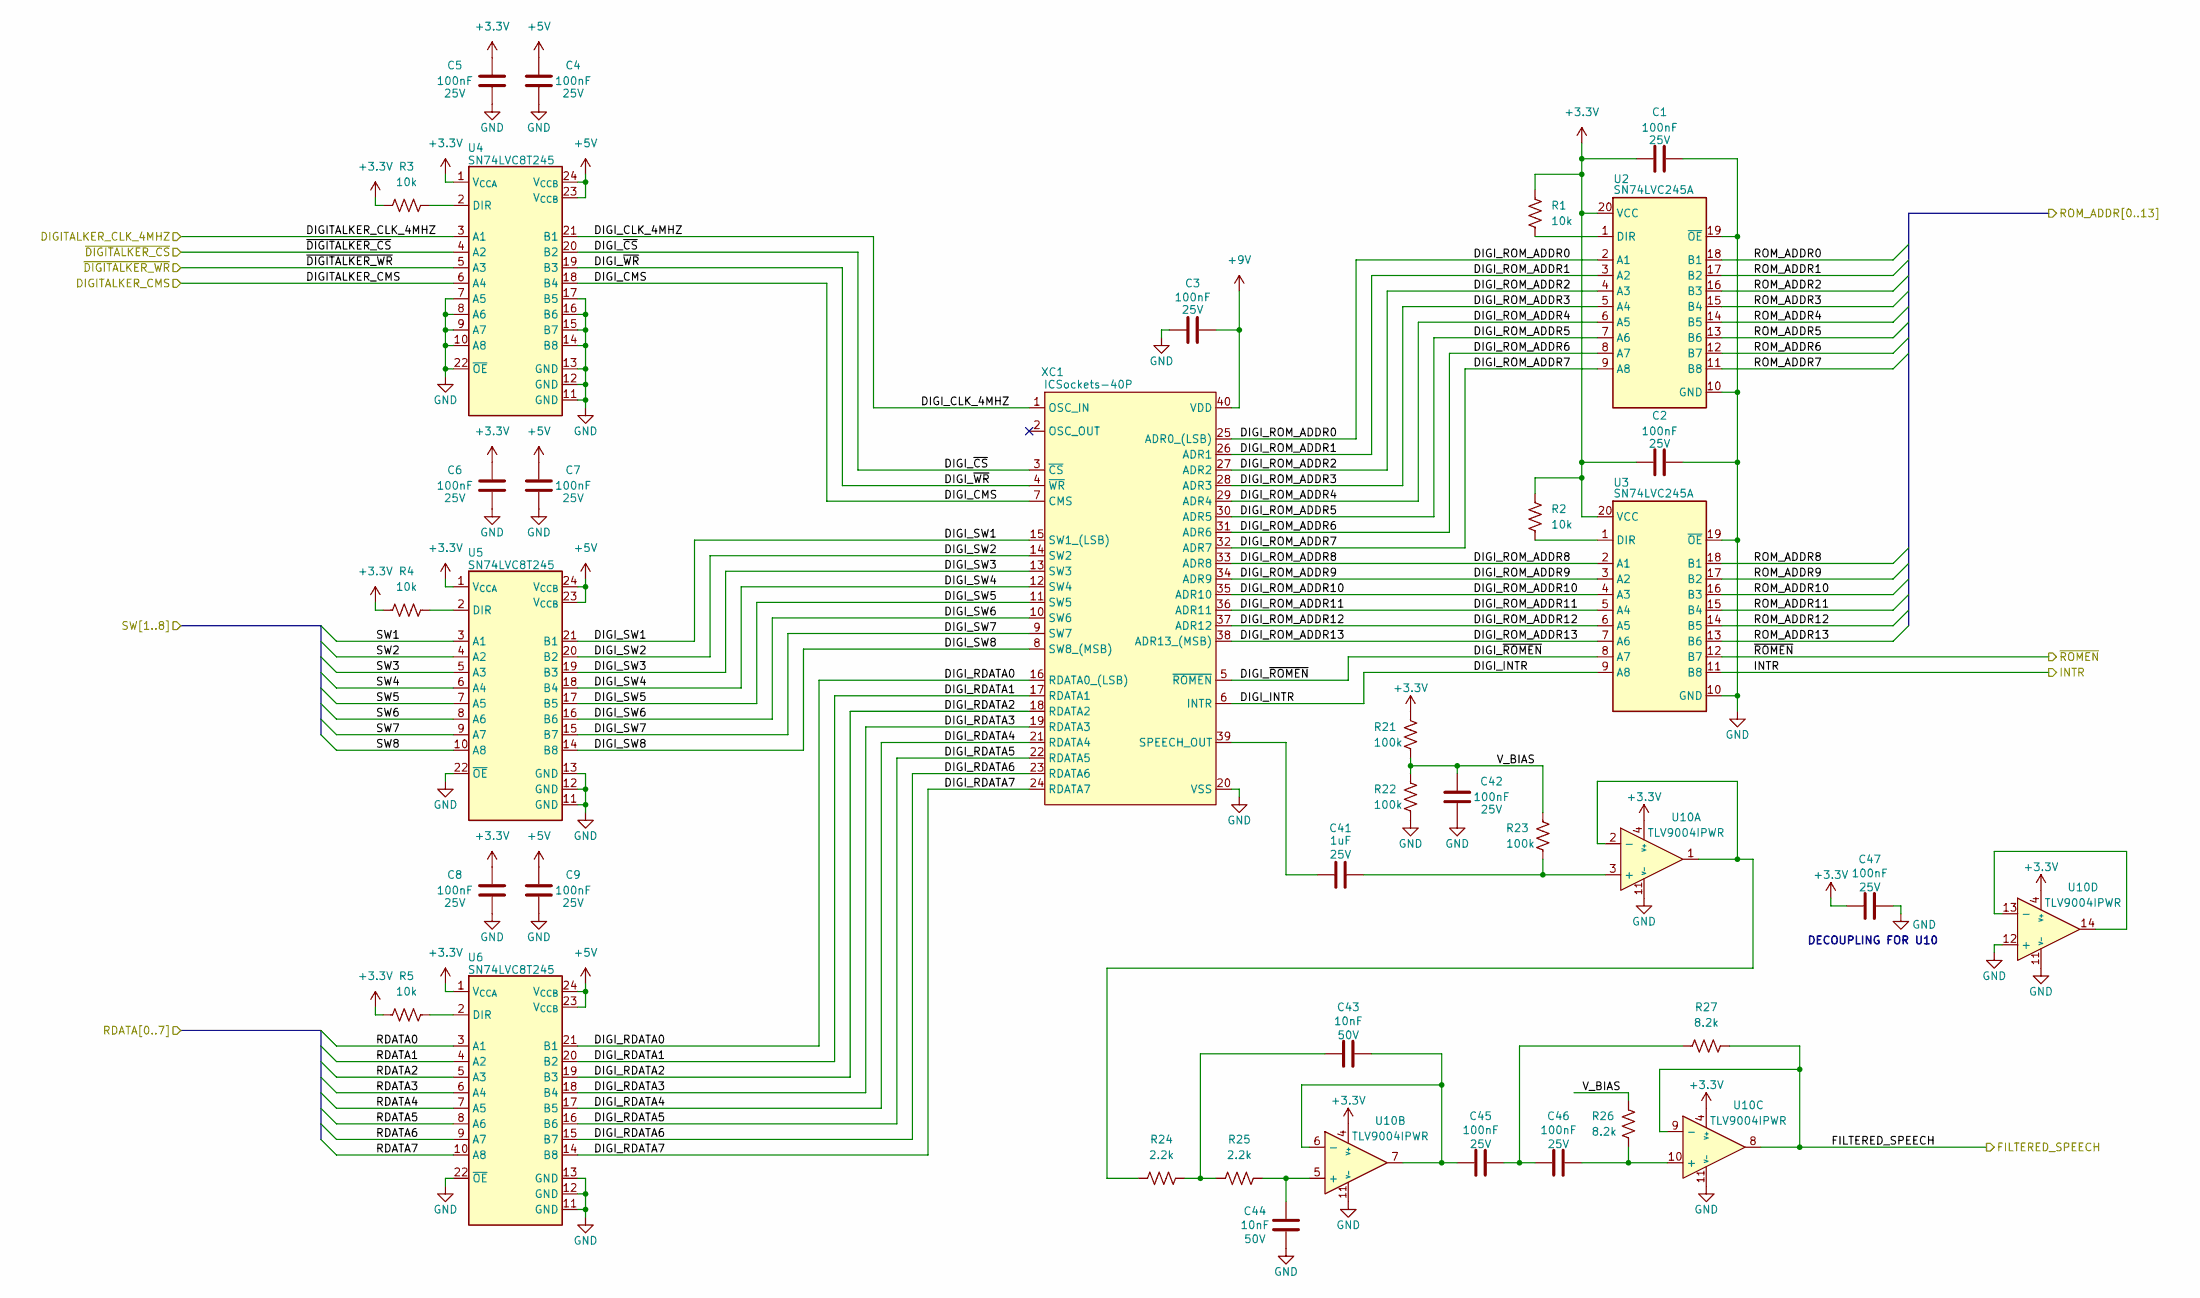
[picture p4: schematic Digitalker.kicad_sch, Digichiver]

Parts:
C1, C2, C3, C4, C5, C6, C7, C8, C9, C42, C45, C46, C47: 100nF; C_0402_1005Metric; Voltage 25V; MPN CL05B104KB54PNC; JLCPCB Part # C307331
C41: 1uF; C_0402_1005Metric; Voltage 25V; MPN CL05A105KA5NQNC; JLCPCB Part # C52923
C43, C44: 10nF; C_0402_1005Metric; Voltage 50V; MPN CL05B103KB5NNNC; JLCPCB Part # C15195
R1, R2, R3, R4, R5: 10k; R_0402_1005Metric; MPN 0402WGF1002TCE; JLCPCB Part # C25744
R21, R22, R23: 100k; R_0402_1005Metric; MPN 0402WGF1003TCE; JLCPCB Part # C25741
R24, R25: 2.2k; R_0402_1005Metric; MPN 0402WGF2201TCE; JLCPCB Part # C25879
R26, R27: 8.2k; R_0402_1005Metric; MPN 0402WGF8201TCE; JLCPCB Part # C25924
U2, U3: SN74LVC245A; TSSOP-20_4.4x6.5mm_P0.65mm; MPN SN74LVC245APWR; JLCPCB Part # C7848
U4, U5, U6: SN74LVC8T245; TSSOP-24_4.4x7.8mm_P0.65mm; MPN SN74LVC8T245PWR; JLCPCB Part # C27643
U10: TLV9004IPWR; TSSOP-14_4.4x5mm_P0.65mm; MPN TLV9004IPWR; JLCPCB Part # C2058050
XC1: ICSockets-40P; DIP-40_W15.24mm_Socket; MPN ICSockets-40P; JLCPCB Part # C2332

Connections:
+3.3V: C1.2, C2.2, C5.1, C6.1, C8.1, C47.2, R1.2, R2.2, R3.2, R4.2, R5.2, R21.2, U2.20 (VCC), U3.20 (VCC), U4.1 (V_{CCA}), U5.1 (V_{CCA}), U6.1 (V_{CCA}), U10.4 (V+); also elsewhere on the board
+5V: C4.1, C7.1, C9.1, U4.23 (V_{CCB}), U4.24 (V_{CCB}), U5.23 (V_{CCB}), U5.24 (V_{CCB}), U6.23 (V_{CCB}), U6.24 (V_{CCB}); also elsewhere on the board
+9V: C3.1, XC1.40 (VDD); also elsewhere on the board
/DIGITALKER_CLK_4MH: U4.3 (A1); also elsewhere on the board
/DIGITALKER_CMS: U4.6 (A4); also elsewhere on the board
/Digitalker/DIGI_CLK_4MHZ: U4.21 (B1), XC1.1 (OSC_IN)
/Digitalker/DIGI_CMS: U4.18 (B4), XC1.7 (CMS)
/Digitalker/DIGI_INTR: U3.9 (A8), XC1.6 (INTR)
/Digitalker/DIGI_RDATA0: U6.21 (B1), XC1.16 (RDATA0_(LSB))
/Digitalker/DIGI_RDATA1: U6.20 (B2), XC1.17 (RDATA1)
/Digitalker/DIGI_RDATA2: U6.19 (B3), XC1.18 (RDATA2)
/Digitalker/DIGI_RDATA3: U6.18 (B4), XC1.19 (RDATA3)
/Digitalker/DIGI_RDATA4: U6.17 (B5), XC1.21 (RDATA4)
/Digitalker/DIGI_RDATA5: U6.16 (B6), XC1.22 (RDATA5)
/Digitalker/DIGI_RDATA6: U6.15 (B7), XC1.23 (RDATA6)
/Digitalker/DIGI_RDATA7: U6.14 (B8), XC1.24 (RDATA7)
/Digitalker/DIGI_ROM_ADDR0: U2.2 (A1), XC1.25 (ADR0_(LSB))
/Digitalker/DIGI_ROM_ADDR1: U2.3 (A2), XC1.26 (ADR1)
/Digitalker/DIGI_ROM_ADDR2: U2.4 (A3), XC1.27 (ADR2)
/Digitalker/DIGI_ROM_ADDR3: U2.5 (A4), XC1.28 (ADR3)
/Digitalker/DIGI_ROM_ADDR4: U2.6 (A5), XC1.29 (ADR4)
/Digitalker/DIGI_ROM_ADDR5: U2.7 (A6), XC1.30 (ADR5)
/Digitalker/DIGI_ROM_ADDR6: U2.8 (A7), XC1.31 (ADR6)
/Digitalker/DIGI_ROM_ADDR7: U2.9 (A8), XC1.32 (ADR7)
/Digitalker/DIGI_ROM_ADDR8: U3.2 (A1), XC1.33 (ADR8)
/Digitalker/DIGI_ROM_ADDR9: U3.3 (A2), XC1.34 (ADR9)
/Digitalker/DIGI_ROM_ADDR10: U3.4 (A3), XC1.35 (ADR10)
/Digitalker/DIGI_ROM_ADDR11: U3.5 (A4), XC1.36 (ADR11)
/Digitalker/DIGI_ROM_ADDR12: U3.6 (A5), XC1.37 (ADR12)
/Digitalker/DIGI_ROM_ADDR13: U3.7 (A6), XC1.38 (ADR13_(MSB))
/Digitalker/DIGI_SW1: U5.21 (B1), XC1.15 (SW1_(LSB))
/Digitalker/DIGI_SW2: U5.20 (B2), XC1.14 (SW2)
/Digitalker/DIGI_SW3: U5.19 (B3), XC1.13 (SW3)
/Digitalker/DIGI_SW4: U5.18 (B4), XC1.12 (SW4)
/Digitalker/DIGI_SW5: U5.17 (B5), XC1.11 (SW5)
/Digitalker/DIGI_SW6: U5.16 (B6), XC1.10 (SW6)
/Digitalker/DIGI_SW7: U5.15 (B7), XC1.9 (SW7)
/Digitalker/DIGI_SW8: U5.14 (B8), XC1.8 (SW8_(MSB))
/Digitalker/DIGI_~CS: U4.20 (B2), XC1.3 (~CS)
/Digitalker/DIGI_~ROMEN: U3.8 (A7), XC1.5 (~ROMEN)
/Digitalker/DIGI_~WR: U4.19 (B3), XC1.4 (~WR)
/Digitalker/FILTERED_SPEECH: R27.1, U10.8, U10.9 (-); also elsewhere on the board
/Digitalker/V_BIAS: C42.1, R21.1, R22.2, R23.2, R26.2
/INTR: U3.11 (B8); also elsewhere on the board
/RDATA0: U6.3 (A1); also elsewhere on the board
/RDATA1: U6.4 (A2); also elsewhere on the board
/RDATA2: U6.5 (A3); also elsewhere on the board
/RDATA3: U6.6 (A4); also elsewhere on the board
/RDATA4: U6.7 (A5); also elsewhere on the board
/RDATA5: U6.8 (A6); also elsewhere on the board
/RDATA6: U6.9 (A7); also elsewhere on the board
/RDATA7: U6.10 (A8); also elsewhere on the board
/ROM_ADDR0: U2.18 (B1); also elsewhere on the board
/ROM_ADDR1: U2.17 (B2); also elsewhere on the board
/ROM_ADDR2: U2.16 (B3); also elsewhere on the board
/ROM_ADDR3: U2.15 (B4); also elsewhere on the board
/ROM_ADDR4: U2.14 (B5); also elsewhere on the board
/ROM_ADDR5: U2.13 (B6); also elsewhere on the board
/ROM_ADDR6: U2.12 (B7); also elsewhere on the board
/ROM_ADDR7: U2.11 (B8); also elsewhere on the board
/ROM_ADDR8: U3.18 (B1); also elsewhere on the board
/ROM_ADDR9: U3.17 (B2); also elsewhere on the board
/ROM_ADDR10: U3.16 (B3); also elsewhere on the board
/ROM_ADDR11: U3.15 (B4); also elsewhere on the board
/ROM_ADDR12: U3.14 (B5); also elsewhere on the board
/ROM_ADDR13: U3.13 (B6); also elsewhere on the board
/SW1: U5.3 (A1); also elsewhere on the board
/SW2: U5.4 (A2); also elsewhere on the board
/SW3: U5.5 (A3); also elsewhere on the board
/SW4: U5.6 (A4); also elsewhere on the board
/SW5: U5.7 (A5); also elsewhere on the board
/SW6: U5.8 (A6); also elsewhere on the board
/SW7: U5.9 (A7); also elsewhere on the board
/SW8: U5.10 (A8); also elsewhere on the board
/~DIGITALKER_CS: U4.4 (A2); also elsewhere on the board
/~DIGITALKER_WR: U4.5 (A3); also elsewhere on the board
/~ROMEN: U3.12 (B7); also elsewhere on the board
GND: C1.1, C2.1, C3.2, C4.2, C5.2, C6.2, C7.2, C8.2, C9.2, C42.2, C44.2, C47.1, R22.1, U2.10 (GND), U2.19 (~OE), U3.10 (GND), U3.19 (~OE), U4.7 (A5), U4.8 (A6), U4.9 (A7), U4.10 (A8), U4.11 (GND), U4.12 (GND), U4.13 (GND), U4.14 (B8), U4.15 (B7), U4.16 (B6), U4.17 (B5), U4.22 (~OE), U5.11 (GND), U5.12 (GND), U5.13 (GND), U5.22 (~OE), U6.11 (GND), U6.12 (GND), U6.13 (GND), U6.22 (~OE), U10.11 (V-), U10.12 (+), XC1.20 (VSS); also elsewhere on the board
unnamed: C43.2, R24.1, R25.2
unnamed: C45.1, C46.2, R27.2
unnamed: R1.1, U2.1 (DIR)
unnamed: R2.1, U3.1 (DIR)
unnamed: R3.1, U4.2 (DIR)
unnamed: R4.1, U5.2 (DIR)
unnamed: R5.1, U6.2 (DIR)
unnamed: C41.1, R23.1, U10.3 (+)
unnamed: R24.2, U10.1, U10.2 (-)
unnamed: C44.1, R25.1, U10.5 (+)
unnamed: C43.1, C45.2, U10.6 (-), U10.7
unnamed: C46.1, R26.1, U10.10 (+)
unnamed: U10.13 (-), U10.14
unnamed: C41.2, XC1.39 (SPEECH_OUT)

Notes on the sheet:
DECOUPLING FOR U10

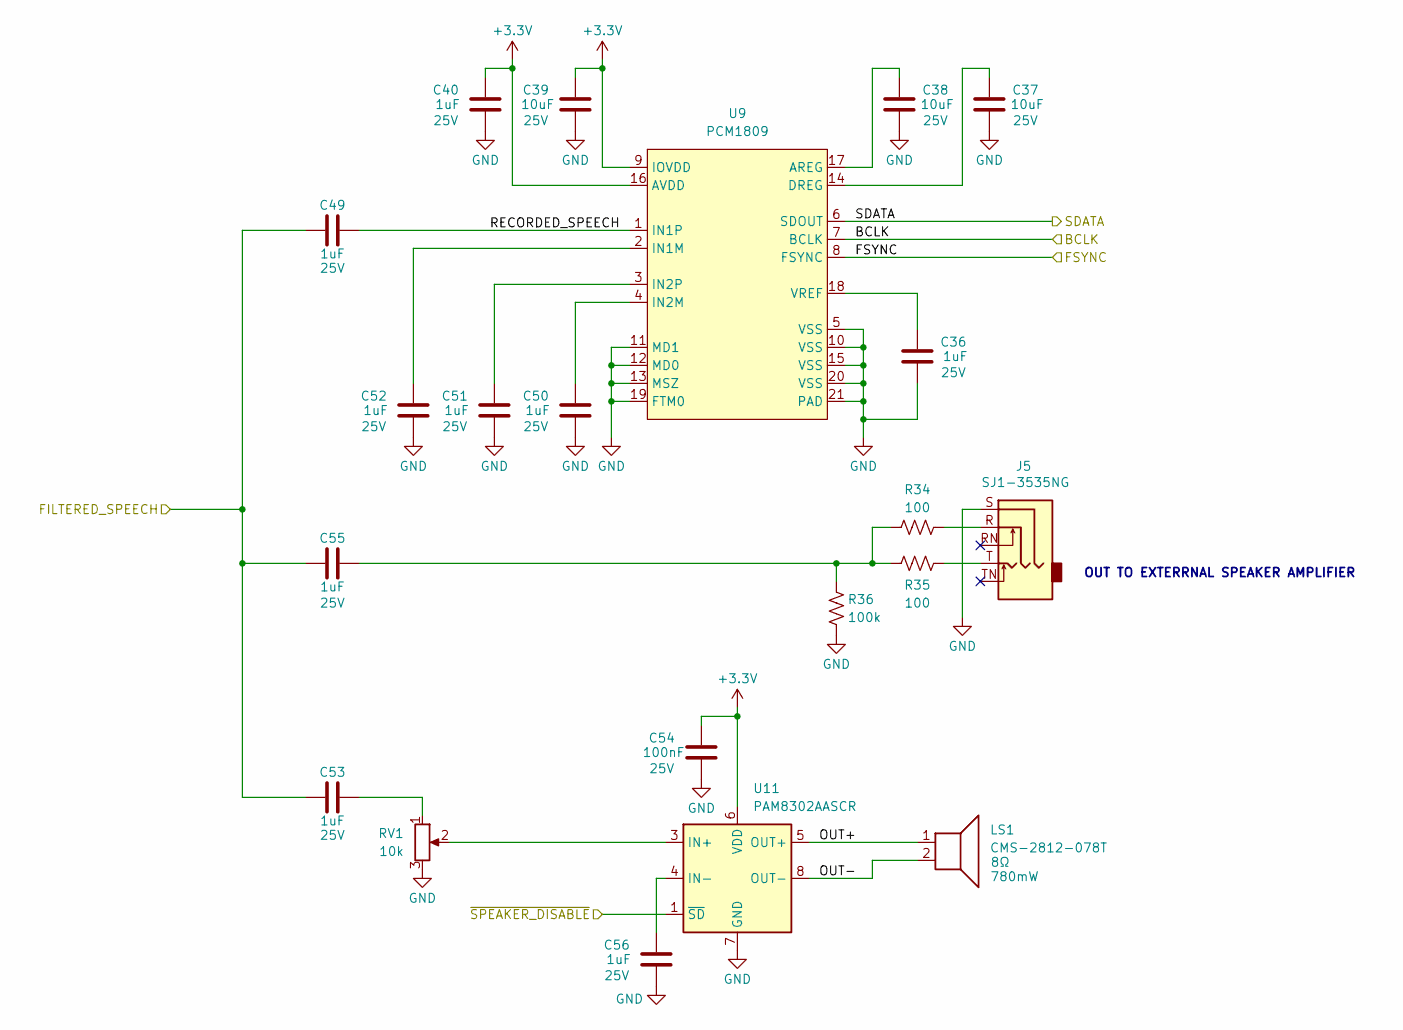
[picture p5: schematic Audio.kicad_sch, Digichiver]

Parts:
C36, C40, C49, C50, C51, C52, C53, C55, C56: 1uF; C_0402_1005Metric; Voltage 25V; MPN CL05A105KA5NQNC; JLCPCB Part # C52923
C37, C38, C39: 10uF; C_0603_1608Metric; Voltage 25V; MPN CL10A106MA8NRNC; JLCPCB Part # C96446
C54: 100nF; C_0402_1005Metric; Voltage 25V; MPN CL05B104KB54PNC; JLCPCB Part # C307331
J5: SJ1-3535NG; Jack_3.5mm_CUI_SJ1-3535NG_Horizontal; MPN SJ1-3535NG; JLCPCB Part # C4991610
LS1: CMS-2812-078T; SPKR_CMS-2812-078T; MPN CMS-2812-078T
R34, R35: 100; R_0402_1005Metric; MPN 0402WGF1000TCE; JLCPCB Part # C25076
R36: 100k; R_0402_1005Metric; MPN 0402WGF1003TCE; JLCPCB Part # C25741
RV1: 10k; PTV09; MPN PTV09A-4015F-A103
U9: PCM1809; PCM1820IRTER; MPN PCM1809IRTER; JLCPCB Part # C38558044
U11: PAM8302AASCR; MSOP-8_3x3mm_P0.65mm; MPN PAM8302AASCR; JLCPCB Part # C113367

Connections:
+3.3V: C39.1, C40.1, C54.1, U9.9 (IOVDD), U9.16 (AVDD), U11.6 (VDD); also elsewhere on the board
/Audio/OUT+: LS1.1, U11.5 (OUT+)
/Audio/OUT-: LS1.2, U11.8 (OUT-)
/Audio/RECORDED_SPEECH: C49.1, U9.1 (IN1P)
/BCLK: U9.7 (BCLK); also elsewhere on the board
/Digitalker/FILTERED_SPEECH: C49.2, C53.2, C55.2; also elsewhere on the board
/FSYNC: U9.8 (FSYNC); also elsewhere on the board
/SDATA: U9.6 (SDOUT); also elsewhere on the board
/~SPEAKER_DISABLE: U11.1 (~SD); also elsewhere on the board
GND: C36.2, C37.2, C38.2, C39.2, C40.2, C50.2, C51.2, C52.2, C54.2, C56.2, J5.S, R36.2, RV1.3, U9.5 (VSS), U9.10 (VSS), U9.11 (MD1), U9.12 (MD0), U9.13 (MSZ), U9.15 (VSS), U9.19 (FTM0), U9.20 (VSS), U9.21 (PAD), U11.7 (GND); also elsewhere on the board
unnamed: C53.1, RV1.1
unnamed: C55.1, R34.2, R35.2, R36.1
unnamed: J5.R, R34.1
unnamed: J5.T, R35.1
unnamed: C38.1, U9.17 (AREG)
unnamed: C37.1, U9.14 (DREG)
unnamed: C52.1, U9.2 (IN1M)
unnamed: C50.1, U9.4 (IN2M)
unnamed: C51.1, U9.3 (IN2P)
unnamed: C36.1, U9.18 (VREF)
unnamed: RV1.2, U11.3 (IN+)
unnamed: C56.1, U11.4 (IN-)

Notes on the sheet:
OUT TO EXTERRNAL SPEAKER AMPLIFIER

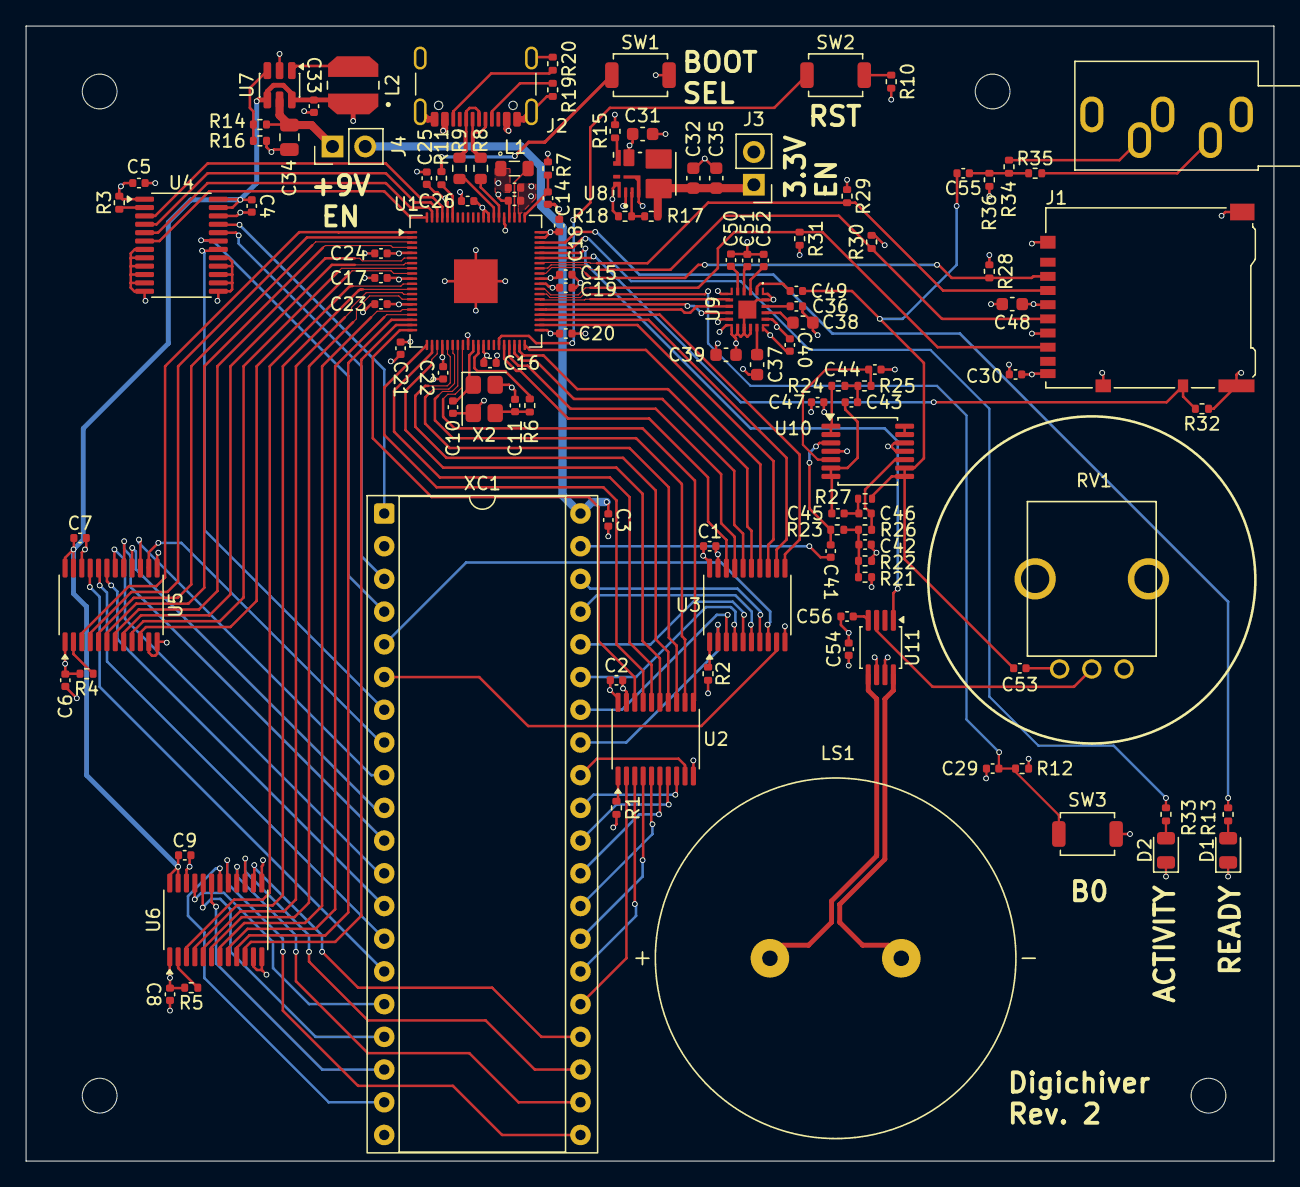
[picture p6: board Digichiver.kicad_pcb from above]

Board: 4 copper layers, 96.9 x 88.1 mm, 121 parts (0 on the bottom side), 143 nets.

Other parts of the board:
MNT1, MNT2, MNT3, MNT4: MountingHole_2.7mm_M2.5

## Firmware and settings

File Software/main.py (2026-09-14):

"""Interactive Digitalker command entry point."""

from archive import ArchiveError, archive_group
from board import LED_GREEN, SPEAKER_DISABLE_N
from digitalker import Digitalker
from free_speak import FreeSpeakError, free_speak, say_all
from rom_emulator import RomEmulator


def handle_command(command: str, rom: RomEmulator, digitalker: Digitalker, COMMANDS: list) -> bool:
    """Handle one command from the interactive command loop.
    Disables green LED during the command execution to indicate the system is busy.

    Args:
        command (str): A command such as ``/say hello`` or ``/say_all``.
        rom (RomEmulator): The ROM emulator used by the speech commands.
        digitalker (Digitalker): The Digitalker driver used by the speech commands.
        COMMANDS (list): A list of known commands for error reporting.

    Returns:
        bool: True when a known command was handled, otherwise False.

    Raises:
        FreeSpeakError: If a speech command contains invalid or unknown words.
    """
    LED_GREEN.value(0)  # Turn off the green LED to indicate the system is busy
    
    command = command.strip()
    
    # Return False if command is not in command list
    if command not in COMMANDS and not any(command.startswith(cmd + " ") for cmd in COMMANDS):
        LED_GREEN.value(1)  # Turn on the green LED to indicate the system is ready
        return False        # Command was not handled
    
    if command == "/help":
        print("Available commands:")
        print("  /archive <group>          - Archive a ROM group to the SD card.")
        print("  /exit or /quit           - Exit the interactive command loop.")
        print("  /help                     - Show available commands.")
        print("  /load_rom <file1> [file2] - Load one ROM image or two 8 KiB bank files.")
        print("  /say <text>              - Speak the specified text using the Digitalker.")
        print("  /say_all                 - Speak all words in the free-speak dictionary.")
        print("  /say_index <start> [end] - Speak word(s) at index or index range (0-255).")
    
    # Handle speech commands in a try-finally block to ensure the speaker is disabled 
    # and the LED is turned on if an error occurs
    try:
        SPEAKER_DISABLE_N.value(1)
        if command.startswith("/archive "):
            archive_group(command[9:].strip(), rom, digitalker)
        elif command == "/load_rom" or command.startswith("/load_rom "):
            args = command[9:].strip().split()
            if len(args) not in (1, 2):
                print("Usage: /load_rom <file1> [file2]")
            else:
                try:
                    rom.load(*args)
                except (OSError, RuntimeError, ValueError) as error:
                    print(f"Failed to load ROM: {error}")
        elif command == "/say_index" or command.startswith("/say_index "):
            if not getattr(rom, "running", False):
                print("No ROM loaded. Use /load_rom <file1> [file2] first.")
            else:
                args = command[10:].strip().split()
                if len(args) not in (1, 2):
                    print("Usage: /say_index <start> [end]")
                else:
                    try:
                        start = int(args[0], 0)
                        end = int(args[1], 0) if len(args) == 2 else start
                        if not (0 <= start <= 255):
                            print(f"Index out of range: {start} (must be 0-255)")
                        elif not (0 <= end <= 255):
                            print(f"Index out of range: {end} (must be 0-255)")
                        elif start > end:
                            print(f"Invalid range: start ({start}) cannot be greater than end ({end})")
                        else:
                            for idx in range(start, end + 1):
                                digitalker.speak_word(idx)
                    except ValueError:
                        print(f"Invalid index: {' '.join(args)!r} (must be integer(s) 0-255)")
        elif command == "/say_all":
            say_all(rom, digitalker)
        elif command == "/say" or command.startswith("/say "):
            free_speak(command[4:].strip(), rom, digitalker)
    finally:
        LED_GREEN.value(1)
        SPEAKER_DISABLE_N.value(0)
    
    SPEAKER_DISABLE_N.value(0)  # Disable the speaker after the command
    LED_GREEN.value(1)          # Turn on the green LED to indicate the system is ready
    return True                 # Command was handled

def print_banner():
    print("=====================================================")
    print(" DIGICHIVER - MM54104 Speech Processor & Archiver   ")
    print("=====================================================")

def main() -> None:
    """Run the interactive command loop."""
    print_banner()
    
    rom = RomEmulator()
    digitalker = Digitalker()
    COMMANDS = ["/archive", "/help", "/load_rom", "/say_index", "/say", "/say_all"]
    prompt = "digichiver> "

    # Turn on the green LED to indicate the system is ready
    LED_GREEN.value(1)

    # Run the REPL until /exit or /quit is entered
    while True:
        command = input(prompt)
        if command in ("/quit", "/exit"):
            LED_GREEN.value(0)
            return
        try:
            if not handle_command(command, rom, digitalker, COMMANDS):
                print(f"unknown command; available commands: {', '.join(COMMANDS)}")
        except (FreeSpeakError, ArchiveError) as error:
            print(error)
            SPEAKER_DISABLE_N.value(0)  # Disable speaker after an error
            LED_GREEN.value(1)          # Turn on the green LED to indicate the system is ready

if __name__ == "__main__":
    main()

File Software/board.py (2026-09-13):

from machine import PWM, Pin

### Digitalker ###
# Explicit output values are required here: a pull-up does not define the
# output latch while the pin is in output mode.  Keep the Digitalker deselected
# and its write strobe inactive before its clock is enabled.
DIGITALKER_CS_N = Pin(1, Pin.OUT, value=1)
DIGITALKER_WR_N = Pin(2, Pin.OUT, value=1)
DIGITALKER_CMS = Pin(3, Pin.OUT, value=1)
SW = [Pin(i, Pin.OUT, value=0) for i in range(4, 12)]
DIGITALKER_CLK_4MHZ = PWM(Pin(0, Pin.OUT), freq=4_000_000)
DIGITALKER_CLK_4MHZ.duty_u16(0)
INTR = Pin(35, Pin.IN)

### ROM Emulator ###
ROM_ADDR = [Pin(i, Pin.IN) for i in range(20, 34)]
ROMEN_N = Pin(34, Pin.IN)
RDATA = [Pin(i, Pin.OUT) for i in range(12, 20)]

# I2S Bus
BCLK = Pin(36, Pin.OUT)
FSYNC = Pin(37, Pin.OUT)
SDATA = Pin(38, Pin.IN)

# microSD
SD_MISO = Pin(40, Pin.IN)
SD_CS_N = Pin(41, Pin.OUT)
SD_SCK = Pin(42, Pin.OUT)
SD_MOSI = Pin(43, Pin.OUT)
SD_DET = Pin(44, Pin.IN)

# GPIO
SPEAKER_DISABLE_N = Pin(45, Pin.OUT, value=0)
LED_ORANGE = Pin(46, Pin.OUT)
LED_GREEN = Pin(47, Pin.OUT)
BUTTON = Pin(39, Pin.IN)

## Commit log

2026-07-25 fix kicad project hierarchy
    [Digitalker.kicad_sch, Power.kicad_sch, block_diagram.kicad_sch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]
2026-07-27 digitalker work
    [Digitalker.kicad_sch, control.kicad_sch, digichiver.kicad_sch]
2026-07-27 bus connections to digitalker output level shifters
    [Digitalker.kicad_sch]
2026-07-28 finish digitalker
    [Digitalker.kicad_sch, control.kicad_sch, digichiver.kicad_sch]
2026-07-28 add RP2354B crystal
    [control.kicad_sch]
2026-07-28 RP2354B noconns
    [control.kicad_sch]
2026-07-28 RP3254B power connections
    [Power.kicad_sch, control.kicad_sch]
2026-07-29 RP2354B interfaces
    [control.kicad_sch]
2026-07-31 block diagram layout
    [digichiver.kicad_sch]
2026-07-31 simulate speech filter
2026-07-31 implement speech filter
    [Digitalker.kicad_sch]
2026-07-31 implement PCM1809
    [Audio.kicad_sch, digichiver.kicad_sch]
2026-07-31 rename files
    [Control.kicad_sch, Digichiver.kicad_pcb, Digichiver.kicad_sch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]
2026-07-31 file renaming
    [Audio.kicad_sch, Control.kicad_sch, Digichiver.kicad_sch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]
2026-07-31 fix reset and bootsel pulldowns
    [Control.kicad_sch]
2026-07-31 decouple SD card
    [Control.kicad_sch]
2026-07-31 SD_DET tweak
    [Control.kicad_sch]
2026-07-31 resize power block
    [Digichiver.kicad_sch]
2026-08-01 speaker output
    [Audio.kicad_sch, Control.kicad_sch, Digichiver.kicad_sch]
2026-08-01 finalize audio outputs
    [Audio.kicad_sch, Digichiver.kicad_sch]
2026-08-01 footprint assignment
    [Audio.kicad_sch, Control.kicad_sch, Digichiver.kicad_sch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]
2026-08-01 link footprints to symbols
    [Audio.kicad_sch, Control.kicad_sch, Digichiver.kicad_sch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]
2026-08-02 RP2354 placement
    [Control.kicad_sch, Digichiver.kicad_pcb]
2026-08-03 layout complete
    [Audio.kicad_sch, Control.kicad_sch, Digichiver.kicad_pcb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]
2026-08-03 ac couple speaker amp input
    [Audio.kicad_sch, Digichiver.kicad_pcb]
2026-08-03 add title silk
    [Digichiver.kicad_pcb]
2026-08-03 swap D2 to amber, silk text
    [Control.kicad_sch, Digichiver.kicad_pcb]
2026-08-03 generate fab outputs
    [Digichiver-B_Cu.gbr, Digichiver-B_Mask.gbr, Digichiver-B_Paste.gbr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]
2026-08-04 generate outputs
    [Audio.kicad_sch, Control.kicad_sch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]
2026-08-04 comment clarification
    [Audio.kicad_sch]
2026-08-04 final circuit description
2026-08-04 move circuit description to hardware folder
2026-08-11 fix speaker_disable sheet port direction
    [Control.kicad_sch, Digichiver.kicad_sch]
2026-08-18 swap USB pairs
    [Control.kicad_sch]
2026-08-18 bump to rev1
    [Audio.kicad_sch, Control.kicad_sch, Digichiver.kicad_sch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]
2026-08-18 fix SN74LVC8T245 footprint
    [Digitalker.kicad_sch]
2026-08-18 fix power jumper footprints
    [Power.kicad_sch]
2026-08-19 sync layout
    [Digichiver.kicad_pcb]
2026-08-19 update PCM1809 footprint
    [Audio.kicad_sch, Control.kicad_sch, Digichiver.kicad_pcb]
2026-08-19 reset 3V3 -> 5V shifter passives to match original stencil
    [Digichiver.kicad_pcb]
2026-08-19 update orange LED net name
    [Control.kicad_sch, Digichiver.kicad_pcb]
2026-08-20 generate Rev1 outputs
    [Audio.kicad_sch, Digichiver.kicad_pcb]
2026-08-29 allow 2350B pin defs
2026-08-30 init digitalker driver
2026-09-01 rev2
    move all components to top side and update BOM to use basic JLCPCB components when possible
    [Audio.kicad_sch, Control.kicad_sch, Digichiver.kicad_pcb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]
2026-09-12 wait for interrupt in speak_word
2026-09-13 blink active LED during speech
2026-09-13 green led logic
2026-09-13 fix speaker disable logic
    [main.py]
2026-09-13 rework free speak error handling
    [main.py]
2026-09-13 fix comma regex validation
    [free_speak.py]
2026-09-13 fix archiver logic and interfaces
    [archive.py, digitalker.py]
2026-09-13 update 127 to "which" from "switch"
2026-09-14 update circuit description
2026-10-16 ground/power plane border symmetry
    no functional change, just looks prettier
